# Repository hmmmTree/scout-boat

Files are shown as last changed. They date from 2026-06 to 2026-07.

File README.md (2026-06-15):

# Scout-Boat
A boat designed to help map out pollutants in laguna de bay

An autonomous surface vessel engineered to analyze water conditions, manage surface waste, and provide actionable data to mitigate flooding in Taguig City and the Laguna Lake region.

## The Problem: Waterway Management and Flooding
Urban flooding is heavily influenced by the environmental state of local waterways and lakes. Surface waste accumulation contributes to drainage blockages and ecological degradation, directly exacerbating flood risks during heavy rains. To address this specifically in laguna de bay, there is a critical need to understand the exact location for the waste located on the lake.

## The Solution
The Lake Sentinel is an uncrewed, autonomous boat designed to tackle these environmental issues at the source. It serves a purpose:
* **Environmental Monitoring:** Navigating local waterways to map out conditions and collect data on water health.

## Technical Architecture

### Hardware
* **Core Brain:** ESP 32
* **Drive System:** Twin two way 50 amp esc
* **Sensors:** Planning to add PH decter, Turbinity, TDS sensor, etc
* **Chassis:** Custom waterproof housing, 3D printed and coated in surface coat epoxy
* **Operational Sensors:** GPS module

### Software Stack
* **Microcontroller Logic:** C++
* **Computer:** Python

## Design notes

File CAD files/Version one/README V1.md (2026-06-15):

# VERSION ONE

## Overview
For this first prototype, I was able to learn a lot. Enhancing my knowlage of both electrical systems, design, and code. With this being my first marine based project, I learned alot about weight to volume ratios and how maximising this increases efficency. This also exposed me to new tools such as multi-meters, soldering, etc. Furthermore this introduced me to coding two interfances that communicate via wifi.

## Pros
1.  Everything was able to be demoed

## Cons
1.  was not able to float
2.  probe did not function
3.  was leaking
4.  ESC ended up frying

## Future changes
1.  Change seal from oring to gasket
2.  Replace the waterproofing angent with surface coat marine epoxy
3.  Make it bigger
4.  make the probe work

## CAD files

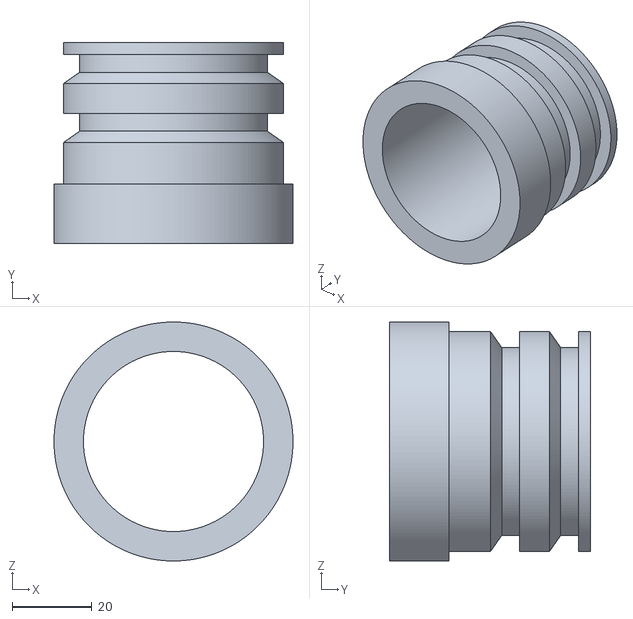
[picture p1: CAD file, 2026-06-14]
CAD files/Version one/main probe V1.stl
60.0 x 50.5 x 60.0

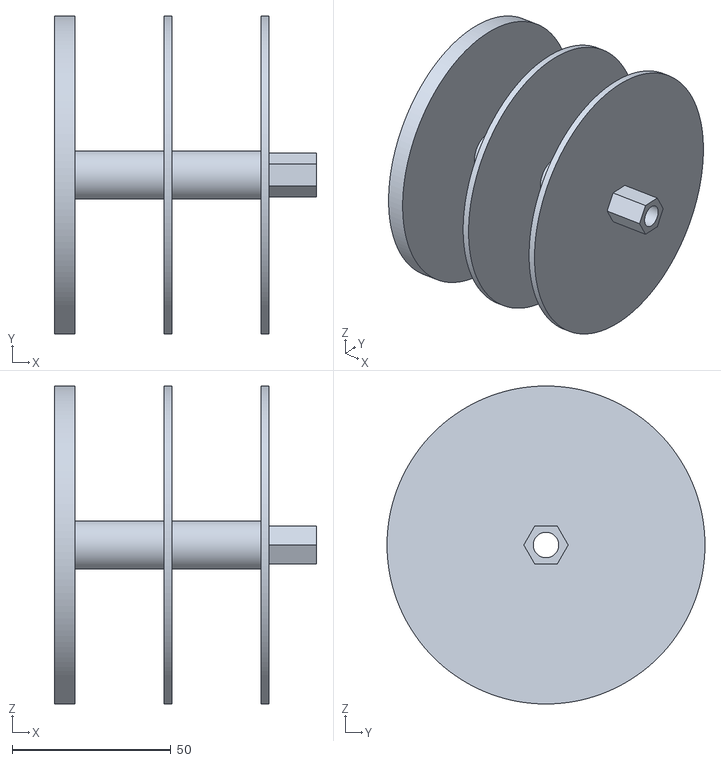
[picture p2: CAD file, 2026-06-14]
CAD files/Version one/pully_string_thing V1.stl
82.5 x 100.0 x 100.0

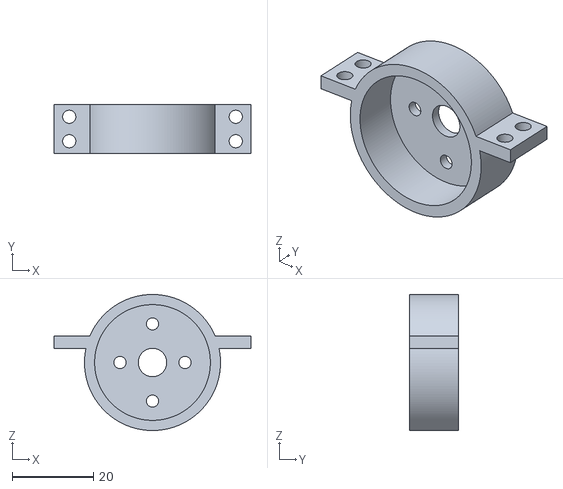
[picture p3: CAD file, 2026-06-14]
CAD files/Version one/motor mount V1.stl
48.5 x 12.0 x 33.5

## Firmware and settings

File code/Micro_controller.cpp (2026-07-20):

/*
 * Boat control receiver
 * ---------------------
 * Pick your board with BOARD below:
 *   0 = classic ESP32 dev board        (Arduino board: "ESP32 Dev Module")
 *   1 = Seeed XIAO ESP32-S3            (Arduino board: "XIAO_ESP32S3", USB CDC On Boot: Enabled)
 *   2 = ESP32-S3 dev board / DevKitC   (Arduino board: "ESP32S3 Dev Module";
 *                                       if flashing via the port labeled "USB",
 *                                       set USB CDC On Boot: Enabled)
 *
 * Protocol: UDP text packets "L:<0-180>,R:<0-180>,W:<0-180>,E:<0|1>" to
 * port 4210. E is the enable flag: E:0 = disarmed -> instant hard stop.
 * Packets without the E field are treated as enabled (old senders).
 *
 * Ack: "OK" plain, or with sensors fitted:
 *   "OK T:<lat>,<lon>,<heading>,<sats>,<speed_ms>,<pitch>,<roll>"
 *
 * Sensors (both optional; firmware auto-detects at boot):
 *   u-blox M10 GPS on UART2      - GPS TX -> GPS_RX_PIN, GPS RX -> GPS_TX_PIN
 *   ICM-20948 9-axis IMU on I2C  - SDA/SCL per board below, 3.3V, addr 0x68/0x69
 *
 * Library Manager installs needed (once):
 *   "TinyGPSPlus" (Mikal Hart)
 *   "SparkFun 9DoF IMU Breakout - ICM 20948"
 * Or set USE_GPS / USE_IMU to 0 to compile without them.
 */

#define BOARD 0   // <-- currently: classic ESP32 dev board
                  //     (esptool identified the chip as plain ESP32)

#define USE_GPS 1
#define USE_IMU 1

// Compass tuning: mounting/declination correction added to heading, and
// hard-iron offsets (uT) from a figure-8 calibration. Zeros work to start.
const float HEADING_OFFSET_DEG = 0.0;
const float MAG_OFF_X = 0.0, MAG_OFF_Y = 0.0, MAG_OFF_Z = 0.0;

#include <WiFi.h>
#include <WiFiUdp.h>
#include <ESP32Servo.h>
#include "soc/soc.h"
#include "soc/rtc_cntl_reg.h"

// ---- WiFi access point ----
const char*    AP_SSID    = "BoatControl";
const char*    AP_PASS    = "boat12345";   // must be at least 8 characters
const uint16_t UDP_PORT   = 4210;
const int      AP_CHANNEL = 6;   // move off crowded default ch1 (lots of nearby APs)

WiFiUDP udp;
char packetBuf[64];

// ---- Servos / ESCs ----
Servo leftSide;
Servo rightSide;
Servo winch;
#if BOARD == 1
// XIAO only breaks out GPIO 1-9 and 43/44 (pads D0-D10); 18/19 don't exist here.
const int leftSidePin  = 2;   // XIAO pad "D1"
const int rightSidePin = 3;   // XIAO pad "D2"
const int winchPin     = 4;   // XIAO pad "D3"
const int I2C_SDA = 5, I2C_SCL = 6;        // pads D4/D5
const int GPS_RX_PIN = 44, GPS_TX_PIN = 43; // pads D7/D6 (free: monitor is USB CDC)
#elif BOARD == 2
// ESP32-S3 devkit: GPIO 19/20 are the USB D-/D+ lines - never use them.
// (Also avoid strap pins 0/3/45/46.) Only the winch moves vs the classic
// ESP32 wiring: 19 -> 4.
const int leftSidePin  = 18;
const int rightSidePin = 5;
const int winchPin     = 4;
const int I2C_SDA = 8, I2C_SCL = 9;
const int GPS_RX_PIN = 16, GPS_TX_PIN = 17;
#else
// Classic ESP32 dev board. Do NOT use 2/3/4 here: GPIO3 is the serial RX pin.
const int leftSidePin  = 18;
const int rightSidePin = 5;
const int winchPin     = 19;
const int I2C_SDA = 21, I2C_SCL = 22;       // board's default I2C pins
const int GPS_RX_PIN = 16, GPS_TX_PIN = 17; // UART2
#endif

// ---- sensors ----
#if USE_GPS
#include <TinyGPSPlus.h>
TinyGPSPlus gps;
HardwareSerial gpsSerial(2);
bool gpsBaudSwitched = false;   // M10 modules ship at 9600 or 38400; autodetect
#endif
#if USE_IMU
#include <Wire.h>
#include <Preferences.h>
#include "ICM_20948.h"
ICM_20948_I2C imu;
bool imuOk = false;
unsigned long lastImuMs = 0;
Preferences prefs;
// live mag offsets: loaded from flash at boot (MAGCAL command refreshes
// them at runtime, no reflash needed). Fall back to the constants above.
float magOffX = 0, magOffY = 0, magOffZ = 0;
// runtime heading reference (HDGREF command: "the bow points north now")
float hdgOff = 0;
float lastMx = 0, lastMy = 0, lastMz = 0;      // raw, for diagnostics
// MAGCAL state: collect raw min/max while the user rotates the boat
bool magCalRunning = false;
unsigned long magCalEndMs = 0, magCalNoteMs = 0;
float cMinX, cMaxX, cMinY, cMaxY, cMinZ, cMaxZ;
#endif
// latest readings for the telemetry ack
float telLat = 0, telLon = 0, telSpd = 0;
float telHdg = 0, telPitch = 0, telRoll = 0;
int   telSats = 0;
bool  telHaveFix = false, telHaveHdg = false;
unsigned long lastStatusMs = 0;   // 5s health print over serial

// ---- Throttle ramp (anti-brownout) ----
// XIAO's small regulator needs a gentle ramp; a dev board can move much faster.
// Stick-to-full-throttle time = 90/RAMP_STEP * RAMP_INTERVAL ms.
int targetL = 90, targetR = 90, targetW = 90;   // where we want to be (from packets)
int curL = 90, curR = 90, curW = 90;            // where the outputs actually are
#if BOARD == 1
const int RAMP_STEP = 1;                        // XIAO: full throttle in ~1.8s
#else
const int RAMP_STEP = 4;                        // devkits: full throttle in ~0.45s
#endif
const unsigned long RAMP_INTERVAL = 20;         // ms between ramp ticks
unsigned long lastRampMs = 0;

// ---- Failsafe ----
unsigned long lastPacketMs = 0;
const unsigned long FAILSAFE_MS = 300;   // no packets for 300ms -> instant stop
bool stopped = true;

// Ramp only applies to power INCREASES. Anything moving toward neutral
// (disarm, stick release, direction change) snaps immediately - reducing
// power is always safe and should never lag.
int stepToward(int cur, int target, int step) {
  if (cur > 90 && target < cur) return (target >= 90) ? target : 90;
  if (cur < 90 && target > cur) return (target <= 90) ? target : 90;
  if (cur < target) {
    cur += step;
    if (cur > target) cur = target;
  } else if (cur > target) {
    cur -= step;
    if (cur < target) cur = target;
  }
  return cur;
}

void hardStop() {
  targetL = targetR = targetW = 90;
  curL = curR = curW = 90;
  leftSide.write(90);
  rightSide.write(90);
  winch.write(90);
}

// Called automatically on WiFi events
void onWiFiEvent(WiFiEvent_t event) {
  if (event == ARDUINO_EVENT_WIFI_AP_STACONNECTED) {
    Serial.println(">>> Computer connected to BoatControl!");
  } else if (event == ARDUINO_EVENT_WIFI_AP_STADISCONNECTED) {
    Serial.println(">>> Computer disconnected.");
  }
}

void setup() {
  WRITE_PERI_REG(RTC_CNTL_BROWN_OUT_REG, 0);   // disable brownout reset (rides through brief dips)
  Serial.begin(115200);

  ESP32PWM::allocateTimer(0);
  ESP32PWM::allocateTimer(1);
  ESP32PWM::allocateTimer(2);
  ESP32PWM::allocateTimer(3);

  leftSide.setPeriodHertz(50);
  leftSide.attach(leftSidePin, 1000, 2000);

  rightSide.setPeriodHertz(50);
  rightSide.attach(rightSidePin, 1000, 2000);

  winch.setPeriodHertz(50);
  winch.attach(winchPin);          // default pulse range (matches your test sketch)

  // Begin holding neutral for the ESCs; the PWM runs in hardware, so the
  // 3s arming window can overlap with the WiFi startup below.
  hardStop();

  // Start the access point immediately so it's visible as soon as possible
  WiFi.mode(WIFI_AP);
  WiFi.onEvent(onWiFiEvent);
  WiFi.softAP(AP_SSID, AP_PASS, AP_CHANNEL);
#if BOARD == 1
  // The XIAO's regulator is small; full 20dBm TX bursts are a common brownout
  // trigger on battery power. 11dBm is still plenty for a few metres of range.
  WiFi.setTxPower(WIFI_POWER_11dBm);
#endif
  WiFi.setSleep(false);            // keep UDP latency low and consistent

  // Finish the ESC arming window (neutral has been held since hardStop above)
  delay(3000);
  Serial.print("Access point started. Join WiFi network: ");
  Serial.println(AP_SSID);
  Serial.print("ESP32 IP address: ");
  Serial.println(WiFi.softAPIP());   // usually 192.168.4.1

  udp.begin(UDP_PORT);
  lastPacketMs = millis();

#if USE_GPS
  gpsSerial.begin(9600, SERIAL_8N1, GPS_RX_PIN, GPS_TX_PIN);
  Serial.println("GPS: listening on UART2 @9600 (autoswitches to 38400)");
#endif
#if USE_IMU
  Wire.begin(I2C_SDA, I2C_SCL);
  Wire.setClock(400000);
  // scan the whole bus first - tells wiring problems from address problems
  Serial.print("I2C scan:");
  int i2cFound = 0;
  for (byte a = 1; a < 127; a++) {
    Wire.beginTransmission(a);
    if (Wire.endTransmission() == 0) {
      Serial.printf(" 0x%02X", a);
      i2cFound++;
    }
  }
  if (!i2cFound) Serial.print(" NOTHING - check wiring/solder joints");
  Serial.println();
  imu.begin(Wire, 1);                    // try addr 0x69 (AD0 high)
  if (imu.status != ICM_20948_Stat_Ok) imu.begin(Wire, 0);   // then 0x68
  imuOk = (imu.status == ICM_20948_Stat_Ok);
  Serial.println(imuOk ? "IMU: ICM-20948 online" : "IMU: not found (telemetry degrades)");
  prefs.begin("boatcal", false);
  magOffX = prefs.getFloat("mx", MAG_OFF_X);
  magOffY = prefs.getFloat("my", MAG_OFF_Y);
  magOffZ = prefs.getFloat("mz", MAG_OFF_Z);
  hdgOff  = prefs.getFloat("ho", HEADING_OFFSET_DEG);
  Serial.printf("MAG offsets: %.1f %.1f %.1f  hdg ref: %+.1f\n",
                magOffX, magOffY, magOffZ, hdgOff);
  Serial.println("(MAGCAL = figure-8 cal, HDGREF = bow-is-north, *CLR to clear)");
#endif
}

// Read sensors and refresh the tel* snapshot used by the ack.
void updateTelemetry() {
#if USE_GPS
  while (gpsSerial.available()) gps.encode(gpsSerial.read());
  // autodetect baud: no NMEA after 5s -> module is at 38400
  if (!gpsBaudSwitched && millis() > 5000 && gps.charsProcessed() < 10) {
    gpsSerial.updateBaudRate(38400);
    gpsBaudSwitched = true;
    Serial.println("GPS: no data at 9600, switched to 38400");
  }
  telHaveFix = gps.location.isValid() && gps.satellites.isValid()
               && gps.satellites.value() >= 4;
  if (telHaveFix) {
    telLat = gps.location.lat();
    telLon = gps.location.lng();
    telSats = gps.satellites.value();
    telSpd = gps.speed.isValid() ? gps.speed.mps() : 0.0f;
  }
#endif
#if USE_IMU
  if (imuOk && millis() - lastImuMs >= 50 && imu.dataReady()) {
    lastImuMs = millis();
    imu.getAGMT();
    float ax = imu.accX(), ay = imu.accY(), az = imu.accZ();
    lastMx = imu.magX(); lastMy = imu.magY(); lastMz = imu.magZ();

    if (magCalRunning) {
      cMinX = min(cMinX, lastMx); cMaxX = max(cMaxX, lastMx);
      cMinY = min(cMinY, lastMy); cMaxY = max(cMaxY, lastMy);
      cMinZ = min(cMinZ, lastMz); cMaxZ = max(cMaxZ, lastMz);
      if (millis() - magCalNoteMs > 3000) {
        magCalNoteMs = millis();
        Serial.printf("MAGCAL: %lus left  spread x=%.0f y=%.0f z=%.0f (want >40 each)\n",
                      (magCalEndMs - millis()) / 1000,
                      cMaxX - cMinX, cMaxY - cMinY, cMaxZ - cMinZ);
      }
      if (millis() >= magCalEndMs) {
        magCalRunning = false;
        magOffX = (cMinX + cMaxX) / 2;
        magOffY = (cMinY + cMaxY) / 2;
        magOffZ = (cMinZ + cMaxZ) / 2;
        prefs.putFloat("mx", magOffX);
        prefs.putFloat("my", magOffY);
        prefs.putFloat("mz", magOffZ);
        Serial.printf("MAGCAL DONE: offsets %.1f %.1f %.1f saved "
                      "(spread %.0f/%.0f/%.0f)\n",
                      magOffX, magOffY, magOffZ,
                      cMaxX - cMinX, cMaxY - cMinY, cMaxZ - cMinZ);
      }
    }

    // AK09916 axes vs accel axes on this chip: y and z are inverted
    float mx = lastMx - magOffX;
    float my = -(lastMy - magOffY);
    float mz = -(lastMz - magOffZ);
    float pitch = atan2f(-ax, sqrtf(ay * ay + az * az));
    float roll  = atan2f(ay, az);
    float xh = mx * cosf(pitch) + mz * sinf(pitch);
    float yh = mx * sinf(roll) * sinf(pitch) + my * cosf(roll)
               - mz * sinf(roll) * cosf(pitch);
    float hdg = atan2f(-yh, xh) * 180.0f / PI + hdgOff;
    while (hdg < 0) hdg += 360.0f;
    while (hdg >= 360.0f) hdg -= 360.0f;
    telHdg = hdg;
    telPitch = pitch * 180.0f / PI;
    telRoll  = roll * 180.0f / PI;
    telHaveHdg = true;
  }
#endif
#if USE_GPS
  // no IMU? fall back to GPS course-over-ground (valid while moving)
  if (!telHaveHdg && telHaveFix && gps.course.isValid()) {
    telHdg = gps.course.deg();
    telHaveHdg = true;
  }
#endif
}

void buildAck(char* out, size_t n) {
  if (telHaveFix || telHaveHdg) {
    snprintf(out, n, "OK T:%.6f,%.6f,%.1f,%d,%.2f,%.1f,%.1f",
             telHaveFix ? telLat : 0.0f, telHaveFix ? telLon : 0.0f,
             telHaveHdg ? telHdg : 0.0f, telHaveFix ? telSats : 0,
             telHaveFix ? telSpd : 0.0f, telPitch, telRoll);
  } else {
    snprintf(out, n, "OK");
  }
}

// Same protocol over WiFi UDP or the USB serial cable. Acks return on
// whichever transport the command arrived on.
void handleCommand(const char* buf, bool fromSerial) {
#if USE_IMU
  if (strcmp(buf, "MAGCAL") == 0) {
    magCalRunning = true;
    magCalEndMs = millis() + 40000;
    magCalNoteMs = 0;
    cMinX = cMinY = cMinZ = 1e9;
    cMaxX = cMaxY = cMaxZ = -1e9;
    Serial.println("MAGCAL: rotate the boat slowly through ALL directions "
                   "(figure-8, roll it too) for 40 seconds...");
    return;
  }
  if (strcmp(buf, "MAGCLR") == 0) {
    magOffX = magOffY = magOffZ = 0;
    prefs.remove("mx"); prefs.remove("my"); prefs.remove("mz");
    Serial.println("MAGCLR: offsets cleared");
    return;
  }
  if (strcmp(buf, "HDGREF") == 0) {
    // the bow points north RIGHT NOW: fold current heading into the offset
    if (telHaveHdg) {
      hdgOff = hdgOff - telHdg;
      while (hdgOff <= -180.0f) hdgOff += 360.0f;
      while (hdgOff > 180.0f) hdgOff -= 360.0f;
      prefs.putFloat("ho", hdgOff);
      Serial.printf("HDGREF: bow = north captured, offset now %+.1f (saved)\n", hdgOff);
    } else {
      Serial.println("HDGREF: no heading available yet");
    }
    return;
  }
  if (strcmp(buf, "HDGCLR") == 0) {
    hdgOff = HEADING_OFFSET_DEG;
    prefs.remove("ho");
    Serial.println("HDGCLR: heading reference cleared");
    return;
  }
#endif
  int l, r, w, en = 1;
  int n = sscanf(buf, "L:%d,R:%d,W:%d,E:%d", &l, &r, &w, &en);
  if (n < 3) return;
  if (n < 4) en = 1;                 // old senders without E: = enabled
  lastPacketMs = millis();

  if (en) {
    targetL = constrain(l, 0, 180);
    targetR = constrain(r, 0, 180);
    targetW = constrain(w, 0, 180);
    stopped = false;
  } else {
    hardStop();                      // disarmed: everything off NOW, no ramp
    stopped = true;
  }

  char ack[112];
  buildAck(ack, sizeof(ack));
  if (fromSerial) {
    Serial.println(ack);
  } else {
    udp.beginPacket(udp.remoteIP(), udp.remotePort());
    udp.print(ack);
    udp.endPacket();
  }
}

char usbBuf[64];
uint8_t usbLen = 0;

void loop() {
  updateTelemetry();

  // ---- wired link: same commands arriving over USB serial ----
  while (Serial.available()) {
    char c = Serial.read();
    if (c == '\n' || c == '\r') {
      if (usbLen) {
        usbBuf[usbLen] = '\0';
        handleCommand(usbBuf, true);
        usbLen = 0;
      }
    } else if (usbLen < sizeof(usbBuf) - 1) {
      usbBuf[usbLen++] = c;
    } else {
      usbLen = 0;                    // garbage line too long: drop it
    }
  }

  // periodic health line so the serial monitor doubles as a sensor check
  if (millis() - lastStatusMs >= 5000) {
    lastStatusMs = millis();
    Serial.print("STATUS:");
#if USE_IMU
    if (imuOk) {
      Serial.printf(" imu=OK hdg=%.0f pitch=%.0f roll=%.0f rawmag=%.0f/%.0f/%.0f",
                    telHdg, telPitch, telRoll, lastMx, lastMy, lastMz);
    } else {
      Serial.print(" imu=MISSING");
    }
#endif
#if USE_GPS
    Serial.printf(" | gps_chars=%lu sentences=%lu sats=%d fix=%s",
                  (unsigned long)gps.charsProcessed(),
                  (unsigned long)gps.sentencesWithFix(),
                  gps.satellites.isValid() ? (int)gps.satellites.value() : -1,
                  telHaveFix ? "YES" : "no");
    if (gps.charsProcessed() < 10) Serial.print("  <- NO DATA: check TX->16 RX->17 wiring");
#endif
    Serial.println();
  }

  // ---- receive commands -> set TARGETS (don't write directly) ----
  int packetSize = udp.parsePacket();
  if (packetSize) {
    int len = udp.read(packetBuf, sizeof(packetBuf) - 1);
    if (len > 0) packetBuf[len] = '\0';

    handleCommand(packetBuf, false);
  }

  // ---- ramp the outputs toward the targets ----
  if (millis() - lastRampMs >= RAMP_INTERVAL) {
    lastRampMs = millis();
    curL = stepToward(curL, targetL, RAMP_STEP);
    curR = stepToward(curR, targetR, RAMP_STEP);
    curW = stepToward(curW, targetW, RAMP_STEP);
    leftSide.write(curL);
    rightSide.write(curR);
    winch.write(curW);
  }

  // ---- failsafe: link gone -> instant stop ----
  if (!stopped && (millis() - lastPacketMs > FAILSAFE_MS)) {
    hardStop();
    stopped = true;
    Serial.print("FAILSAFE: no commands for ");
    Serial.print(FAILSAFE_MS);
    Serial.println("ms - motors stopped");
  }
}

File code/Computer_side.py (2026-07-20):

"""Boat driver station — drive, navigation, camera and 3D attitude view.

Keys / controls:
  F11        fullscreen toggle          SPACE / Square   arm-disarm
  Arrows or L1/R1  speed limit          ESC              exit fullscreen / quit
  I / K / O  winch in/stop/out          M / Options      AUTO <-> TELEOP
  R2/L2 hold winch in/out (momentary)   H                controls reference
  E          EDIT MODE (keyboard only)  F / Share        re-follow boat on map
  Map (always): drag = pan, scroll = zoom.  OSM tiles cache to assets/tiles
  and work offline once downloaded (Philippines overview pre-cached).
  EDIT MODE only: click = add/select waypoint, drag one = move it,
  right-click = delete, DEL = delete selected, [ / ] = hold time -/+5s,
  Ctrl+Z = undo, C = clear all.  Purple pin = this computer (IP location).
  3D view: fixed camera — moves only with the boat's real attitude

Network protocol (UDP to 192.168.4.1:4210):
  send: "L:<0-180>,R:<0-180>,W:<0-180>,E:<0|1>"     50x per second
  recv: "OK"                                        plain ack (current firmware)
        "OK T:<lat>,<lon>,<hdg>,<sats>[,<spd_ms>[,<pitch>,<roll>]]"
        ack with telemetry once the M10 GPS (+ 9-axis IMU) firmware is in:
        map, compass, speed, heading, 3D attitude and missions activate
        automatically when the fields appear.

Camera: set CAMERA_URL to the ESP32-CAM MJPEG stream (default is the
standard ESP32-CAM AP-mode stream address). Panel shows NO CAMERA until
frames arrive.

Windows note: "No internet" on the BoatControl network is normal — the boat
is an access point with no internet behind it.

Requires: pygame-ce (or pygame), numpy. Optional: pyserial for the wired
USB link — if the boat is plugged in and WiFi is silent for 2s, commands
switch to the USB cable automatically (BOAT LINK pill shows "USB");
unplugging falls back to WiFi. Same protocol either way.
The 3D view loads assets/boat_mesh.npz — converted from "Twin v2.step".
"""
import io
import json
import math
import os
import socket
import subprocess
import sys
import threading
import time
import urllib.request
from collections import deque

import numpy as np
import pygame

# Give the 50Hz network thread timely GIL slices even while the 3D
# renderer is busy (default switch interval is 5ms, too coarse here).
sys.setswitchinterval(0.001)

ESP32_IP   = "192.168.4.1"
ESP32_PORT = 4210
SEND_HZ    = 50
BOAT_SSID  = "BoatControl"
CAMERA_URL = "http://192.168.4.10:81/stream"  # XIAO ESP32-S3 Sense (boat_cam.ino)
MODEL_YAW_OFFSET = 0    # degrees; set 180 if the 3D boat renders stern-first

# ---- autonomous mode tuning ----
WP_RADIUS_M   = 3.0    # waypoint reached within this many meters
AUTO_CRUISE   = 0.55   # cruise throttle fraction while on course
AUTO_TURN_GAIN = 0.7   # how hard heading error steers
STICK_OVERRIDE = 0.25  # stick deflection that kicks AUTO back to TELEOP
HOLD_STEP_S   = 5      # [ / ] adjust a waypoint's hold time by this many seconds

# ---- map / tiles ----
TILESIZE = 256
TILE_URL = "https://tile.openstreetmap.org/{z}/{x}/{y}.png"
TILE_UA  = "ScoutBoatDriverStation/1.0 (personal robotics project)"
PH_CENTER = (12.8797, 121.7740)     # Philippines overview
_here = os.path.dirname(os.path.abspath(__file__))
ASSET_DIR = (os.path.join(_here, "assets")
             if os.path.isdir(os.path.join(_here, "assets"))
             else os.path.normpath(os.path.join(_here, "..", "assets")))


def _ll_to_world(lat, lon, z):
    """lat/lon -> Web Mercator pixel coords at zoom z."""
    n = (1 << z) * TILESIZE
    x = (lon + 180.0) / 360.0 * n
    lr = math.radians(clamp(lat, -85.05, 85.05))
    y = (1.0 - math.log(math.tan(lr) + 1.0 / math.cos(lr)) / math.pi) / 2.0 * n
    return x, y


def _world_to_ll(x, y, z):
    n = (1 << z) * TILESIZE
    lon = x / n * 360.0 - 180.0
    lat = math.degrees(math.atan(math.sinh(math.pi * (1.0 - 2.0 * y / n))))
    return lat, lon


def geo_dist_bearing(lat1, lon1, lat2, lon2):
    """meters + compass bearing between nearby points (equirectangular)."""
    x = (lon2 - lon1) * 111320.0 * math.cos(math.radians((lat1 + lat2) / 2.0))
    y = (lat2 - lat1) * 110540.0
    return math.hypot(x, y), math.degrees(math.atan2(x, y)) % 360.0


# ---- user settings (S key panel), persisted to assets/settings.json ----
SETTINGS = {"invert_hdg": False, "invert_roll": False, "invert_pitch": False,
            "mavlink": True}
MAVLINK_PORT = 14550     # Mission Planner: Connect -> UDP -> this port

def load_settings():
    try:
        s = json.load(open(os.path.join(ASSET_DIR, "settings.json")))
        for k in SETTINGS:
            if k in s:
                SETTINGS[k] = bool(s[k])
    except Exception:
        pass

def save_settings():
    try:
        os.makedirs(ASSET_DIR, exist_ok=True)
        json.dump(SETTINGS, open(os.path.join(ASSET_DIR, "settings.json"), "w"))
    except Exception:
        pass
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

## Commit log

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2026-07-19 Tune microcontroller code for Seeed XIAO ESP32-S3
    - Fix motor pins: GPIO18/19 are not broken out on the XIAO
    (19/20 are USB data lines); use D1/D2/D3 (GPIO2/3/4) instead
    - Reduce WiFi TX power to 11dBm and disable modem sleep to
    reduce battery brownouts from TX current spikes
    - Correct failsafe log/comment to match the 750ms timeout
    - Add header documenting Arduino IDE board settings
    [Micro_controller.cpp]
2026-07-19 Use raw GPIO numbers so sketch compiles on any ESP32-S3 board variant
    D1/D2/D3 macros only exist in the XIAO_ESP32S3 board variant; with
    'ESP32S3 Dev Module' selected they fail to compile. GPIO 2/3/4 are
    the same physical pads (silkscreened D1/D2/D3 on the XIAO).
    [Micro_controller.cpp]
2026-07-19 Start WiFi AP before ESC arming delay so network appears sooner
    The 3s ESC arming wait only needs neutral PWM held on the outputs,
    which runs in hardware - so the AP can come up during it instead of
    after it. Cuts ~3s off time-to-visible-network after power-on.
2026-07-19 Driver station: start disarmed, show live WiFi network, GUI polish
    - Motors now always start DISARMED; arm with Square or Space
    - New WIFI NETWORK pill shows the SSID the computer is actually on,
    with a warning line when it isn't BoatControl (Windows silently
    switching back to home WiFi was causing 'boat link lost' confusion;
    'No internet' on BoatControl is normal and now documented)
    - Boat link pill shows ack age in ms; telemetry panel shows ack count
    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
2026-07-19 Support both XIAO ESP32-S3 and classic ESP32 dev board; cut latency
    - BOARD_XIAO_S3 switch selects pins/tuning per board (defaults to
    classic dev board, currently in use):
    XIAO -> GPIO 2/3/4, gentle ramp, 11dBm TX
    DevKit -> GPIO 18/5/19 (original wiring; 2/3/4 would collide
    with serial RX on GPIO3), fast ramp, full TX power
    - Throttle ramp on dev board: full deflection now ~0.45s instead of
    ~1.8s - the ramp was most of the perceived control latency
    - AP now on channel 6 instead of crowded default channel 1
    [Micro_controller.cpp]
2026-07-19 Instant shutoff on disarm and link loss
    - Ramp now only applies to power increases; anything moving toward
    neutral (disarm, stick release, direction change) snaps instantly.
    Disarming used to wind down over the full ramp time.
    - New E:<0|1> enable flag in the packet protocol; driver station sends
    E:0 while disarmed and on exit, boat hard-stops immediately on E:0.
    Packets without E still work (treated as enabled).
    - Failsafe timeout cut 750ms -> 300ms: with 50Hz commands, 300ms of
    silence is a dead link, not jitter - motors stop sooner when WiFi
    drops.
    [Computer_side.py, Micro_controller.cpp]
2026-07-19 Add ESP32-S3 devkit board option (now the active board)
    Three-way BOARD switch: 0=classic ESP32, 1=XIAO ESP32-S3, 2=S3 devkit.
    S3 devkit keeps left/right on GPIO 18/5 but moves winch 19 -> 4, since
    GPIO 19/20 are the USB data lines on the S3. Defaults to BOARD=2 (the
    XIAO got damaged; an S3 devkit is the current hardware).
    [Micro_controller.cpp]
2026-07-19 Default BOARD back to classic ESP32 - esptool identified the chip
    Upload attempt failed with 'This chip is ESP32, not ESP32-S3', so the
    current dev board is a classic ESP32 after all. Pins revert to the
    original 18/5/19 wiring.
    [Micro_controller.cpp]
2026-07-20 Driver station redesign: fullscreen + navigation/mission panel
    - F11 toggles fullscreen; UI renders to a 1280x720 virtual canvas and
    letterbox-scales to any window or monitor size (window is resizable)
    - New navigation panel: local-frame map (meters grid, scroll to zoom)
    with HOME marker, boat trail, boat heading arrow, click-to-add
    waypoints (right-click removes, C clears) and a mission bar
    - Compass rose with live heading; GPS status tile (sats/fix)
    - Ack protocol extended: boat may reply 'OK T:<lat>,<lon>,<hdg>,<sats>'
    once GPS/compass hardware is fitted - map, compass and START MISSION
    unlock automatically when telemetry arrives; until then the map is a
    planning grid and miss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
    [Computer_side.py]
2026-07-20 Driver station: 3D boat view from CAD, camera panel, speed/heading tiles
    - 3D viewport renders the actual Twin v2 hull (STEP converted to a
    4.5k-face mesh in assets/boat_mesh.npz, software-rendered with
    numpy + painter's algorithm). Yaw follows GPS/compass heading,
    pitch/roll follow the 9-axis IMU when telemetry includes them;
    drag to orbit, idle turntable until telemetry exists
    - Camera panel: MJPEG client for an ESP32-CAM stream (CAMERA_URL),
    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
2026-07-20 Firmware: M10 GPS + ICM-20948 telemetry in acks
    - UART2 GPS via TinyGPSPlus with 9600/38400 autodetect (M10 modules
    ship at either); position, sats, speed-over-ground
    - ICM-20948 via SparkFun lib on I2C (tries 0x69 then 0x68):
    accel pitch/roll + tilt-compensated magnetometer heading at 20Hz,
    with hard-iron offset and heading offset constants for calibration
    - Ack becomes 'OK T:lat,lon,hdg,sats,spd,pitch,roll' when any sensor
    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
2026-07-20 Add boat camera firmware for XIAO ESP32-S3 Sense
    - boat_cam (code/Camera_side.cpp): joins BoatControl as a client with
    static IP 192.168.4.10 and serves MJPEG at :81/stream. VGA @ ~20fps
    cap so video doesn't starve the control link. Auto-reconnects.
    - Driver station CAMERA_URL updated to the fixed cam address, so the
    camera panel lights up as soon as the Sense is powered.
    [Camera_side.cpp, Computer_side.py]
2026-07-20 Blueprint-style 3D render, editable waypoints with undo, threaded 50Hz net loop
    - 3D view is now outline-style: flat dark hull fill with silhouette +
    crease edges, hiding tessellation triangles entirely. Mesh asset
    rebuilt from the STEP with clean CAD-native tessellation (8.3k faces,
    453 tiny hardware components dropped) plus precomputed edge adjacency
    - Waypoints are now editable: drag to move (grabbed one highlights
    yellow), right-click deletes that waypoint, Ctrl+Z undoes add/move/
    delete/clear (100-step history)
    - Network commands moved to a dedicated thread with absolute-deadline
    pacing so packet rate no longer depends on GUI frame rate; 3D
    rendering also moved off the mai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
    [Computer_side.py]
2026-07-20 TELEOP/AUTO mode switch with station-side autopilot
    - M key or the START AUTO button toggles modes; mode chip + AUTO tag
    on the map show state at a glance
    - AUTO runs a proportional guidance loop on the station: bearing to
    the active waypoint vs compass heading -> differential thrust, slows
    for large heading errors, 3m arrival radius, advances through the
    route and drops back to TELEOP on completion (verified against a
    simulated differential-thrust boat)
    - Safety interlocks: AUTO only engages when armed + controller present
    + GPS fix + heading + waypoints; moving a stick past 25% instantly
    returns to TELEOP; disarm or controller loss always exits AUTO;
    stale telemetry holds n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
    [Computer_side.py]
2026-07-20 Real OSM map, keyboard-only edit mode with waypoint timing, PC pin
    - Map is now a slippy-tile OpenStreetMap view (Web Mercator): drag to
    pan, scroll to zoom around the cursor, F re-follows the boat. Tiles
    cache to assets/tiles and work fully offline once seen; Philippines
    overview (z5-8) plus detail around the user's city (z9-14) were
    pre-downloaded. Attribution shown; tiles gitignored (local cache).
    - EDIT MODE, toggled only by the E key (ArduPilot flight-planner
    style): click adds/selects waypoints, drag moves, right-click or DEL
    deletes, [ ] adjusts a per-waypoint HOLD time in 5s steps, Ctrl+Z
    undoes everything, and a waypoint table overlays the map with leg
    distances, hol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
    [Computer_side.py]
2026-07-20 Standalone map downloader, full-screen edit mode, winch controls, help panel
    - download_map.py: dedicated offline-tile fetcher (PH overview + detail
    around the PC or --at LAT LON, zoom range flags, polite rate). The
    station only reads the cache these tiles land in.
    - EDIT mode now disables everything: entering it disarms the motors,
    forces TELEOP, hides the whole dashboard and gives the map the full
    window, mission bar across the bottom. E exits back to driving.
    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
2026-07-20 Winch operable from EDIT mode; drive stays hard-locked
    Edit mode now has a winch cluster in the mission bar (IN/STOP/OUT
    buttons, keys I/K/O, DS4 triggers). While editing, every packet pins
    L/R at neutral and the enable flag only rises while the winch is
    commanded, so the drive cannot move — verified at the packet level
    (45/45 winch-run packets carried L:90,R:90).
2026-07-20 Plannable per-waypoint winch actions (ArduPilot DO-command style)
    Waypoints gain a winch action and duration, set in edit mode:
    W cycles — / v OUT / ^ IN / v^ SAMPLE -/= adjusts seconds (1-120)
    On arrival the autopilot executes: probe down (ws) -> dwell (hold) ->
    probe up (ws) -> continue. autopilot_step became a phase machine
    (transit/winch_out/dwell/winch_in) returning a winch override; manual
    winch stays live during transit legs. Verified in simulation: sample
    waypoint ran 1.9s down / 2.9s dwell / 1.9s up in order with correct
    winch commands (0/90/180).
    Waypoint table gains a WINCH column; map pins annotate action+time;
    mission bar shows the selected waypoint's plan. The previou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
    [Computer_side.py]
2026-07-20 Map precision: zoom to z19, cursor/waypoint lat-lon readout
    - Max zoom raised 17 -> 19 (OSM's limit); scale readout switches to
    0.1m resolution when under 10m/100px
    - Map HUD shows live cursor coordinates (6 decimals ~ 11cm) and the
    selected waypoint's exact lat/lon in edit mode
    - download_map.py allows --zmax up to 17 with a tile-count warning
2026-07-20 Print an I2C bus scan at boot to diagnose sensor wiring
    Live board reported 'IMU: not found'; the scan distinguishes a dead
    bus (wiring/solder) from a device on an unexpected address.
2026-07-20 Print 5s sensor health line over serial
    IMU confirmed online on the bench (I2C scan found 0x69) after a
    wiring fix. GPS still shows no NMEA at 9600; the status line reports
    chars/sentences/sats/fix continuously so baud vs wiring issues are
    visible directly in the serial monitor.
    [Micro_controller.cpp]
2026-07-20 Wired USB link: same protocol over the serial cable, auto-switching
    - Firmware accepts the same 'L:..,R:..,W:..,E:..' commands as newline
    lines on USB serial and acks (incl. telemetry) on the same transport;
    refactored shared handleCommand/buildAck for both paths. WiFi UDP
    unchanged; both feed the same failsafe.
    - Station: network worker prefers WiFi; if no acks for 2s and a
    CP210x/CH340 boat is on USB, it switches to the cable (DTR/RTS held
    low to avoid resetting the board), and returns to WiFi when the
    cable disappears or goes silent 3s. BOAT LINK pill shows WiFi/USB;
    status hints updated. pyserial is an optional dependency.
    - Fixed a real thread-safety bug the wire test expo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
    [Computer_side.py, Micro_controller.cpp]
2026-07-20 Compass shows next-waypoint bearing pin
    Orange diamond on the compass rim at the bearing to the next waypoint
    (AUTO's active target, else WP1) - line the cyan needle up with the
    pin and the boat is pointed at its goal. HEADING tile shows the
    numeric bearing and distance (m/km). Requires GPS fix + waypoints.
    [Computer_side.py]
2026-07-20 Fix 3D view to a zeroed camera; show live heading in edit mode
    - Boat 3D panel: drag-to-orbit and the idle turntable are gone. The
    camera is fixed at zero; the model only moves with real telemetry
    attitude and rests facing north without it.
    - Edit mode keeps live heading visible: compass overlay (with the
    next-waypoint bearing pin) + numeric readout on the map corner.
    Telemetry always flowed while disarmed/editing; now it's displayed.
    [Computer_side.py]
2026-07-20 Attitude zeroing: 0 tares heading/pitch/roll, Shift+0 clears
    Press 0 with telemetry live to capture the current pose as zero -
    heading, pitch and roll all become relative to it (heading wraps
    correctly). Calibration persists in assets/attitude_cal.json across
    restarts, applies at the Nav layer so compass, tiles, 3D model, map
    arrow and autopilot all agree, shows a CAL tag on the 3D panel and a
    confirmation toast. Shift+0 clears. Level the boat first - and point
    the bow north if AUTO missions should keep true bearings.
    [Computer_side.py]
2026-07-20 Built-in magnetometer calibration (MAGCAL over serial, saved to NVS)
    Send MAGCAL over the USB link, rotate the boat through all directions
    for 40s; firmware tracks raw min/max per axis, computes hard-iron
    offsets, applies them immediately and persists them in flash
    (Preferences) - no reflash needed afterwards. MAGCLR clears. Progress
    prints every 3s with per-axis spread; STATUS line now includes raw mag
    for axis diagnostics.
2026-07-20 HDGREF command: capture bow-is-north heading reference to flash
    After MAGCAL the heading tracked 1:1 but with a constant ~150deg
    offset (mount rotation + sensor axis convention). Point the bow at
    north and send HDGREF - the firmware folds the current heading into a
    persistent offset (NVS), applied at the source so the station and
    autopilot all see true bearings. HDGCLR resets.
    [Micro_controller.cpp]
2026-07-20 0 key zeroes heading at the source via HDGREF
    Pressing 0 with a live boat link now sends HDGREF - the boat stores
    current-bow = 000 in its flash - and zeroes pitch/roll locally; only
    one heading offset ever exists, so displays and autopilot agree.
    Shift+0 clears both sides (HDGCLR + local cal). Falls back to the old
    local-only zeroing when no link. Numpad 0 works too. Verified the
    one-shot command path over the simulated wire.
2026-07-20 Settings panel (S): invert heading / roll / pitch direction
    Reported heading and roll moving the wrong way (sensor axis
    conventions). S opens a settings overlay with three toggles - click a
    row or press 1/2/3 - persisted to assets/settings.json and applied at
    the telemetry layer before zeroing offsets, so compass, 3D model, map
    and autopilot all agree. Heading inverts as mirror (360-h): north
    stays north, rotation direction flips.
    [Computer_side.py]
2026-07-20 IMU staleness watchdog: frozen heading becomes honest no-heading
    A failing I2C joint mid-run used to freeze telHdg and keep
    transmitting it forever (compass needle stuck). Now: no fresh IMU
    data for 2s -> telemetry stops claiming a heading (station shows --),
    STATUS reports imu=STALE, and the sensor is re-init'd every 5s so a
    loose wire recovers by itself when contact returns.
    [Micro_controller.cpp]
2026-07-20 Revert "IMU staleness watchdog: frozen heading becomes honest no-heading"
    This reverts commit 19fa7a74e78ffddf182b47866f6e73b2e7b0feff.
    [Micro_controller.cpp]
2026-07-20 Manual PC pin: Shift+click the map places it exactly
    IP geolocation lands on the ISP node, not the desk. Shift+click
    anywhere on the map pins the computer's true position (persisted,
    marked manual so the IP locator never overwrites it). Settings row 4
    clears the manual pin and re-detects via IP.
2026-07-20 PC button / P key centers the map on the computer pin
    Small button bottom-right of the map (both normal and edit modes);
    jumps to the PC location at z16 (or keeps deeper zoom), disengages
    boat-follow so it stays put.
2026-07-20 Mission Planner interop: import/export .waypoints missions
    Drag a Mission Planner (QGC WPL 110) .waypoints file onto the station
    to load its route - NAV_WAYPOINT rows become waypoints, per-waypoint
    delay (p1) maps to our hold time, home row and non-nav commands are
    skipped, map jumps to the mission. Ctrl+S exports the current mission
    to assets/missions/ in the same format so it opens in Mission Planner.
    (S alone still opens settings; live MAVLink link would be a separate
    build - this covers plan-there-run-here.)
    [Computer_side.py]
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
